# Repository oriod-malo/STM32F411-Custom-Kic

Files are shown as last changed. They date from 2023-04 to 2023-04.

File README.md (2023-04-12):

# STM32F411-Custom-Kit

#### NOTE (as of April 12th 2023)
#### By Kicad ERC and DRC this board should be functional however it's not manufactured yet for a physical, hands-on testing.

## Description

This is my first fully independent KiCad project after following the tutorial for the STM32F103.
A STM32F411 Discovery board was something I wanted to buy since a long time.
However, I figured out it's better if I learn to make myself something similar and have it assembled.<br>
<br>
Due to component density and pin count, this schematic ended up being a 6-layer board. <br>
<br>
Layer parameters and component choice has been made considering jlcpcb constraints and components library(for the sake of orientation). It can be manufactured by ANY service. <br>
Also feel free to change constraints / components. <br>
<br>
<br>

## Differences between this and actual Discovery Boards.

* Due to unavailability of components, I removed all the audio subsystem that Discovery boards have and replaced it with extra pins

* Again due to components availability some components have been replaced with others and / or similar components

* I have no idea how many layers Discovery Kits actually have, this one has 6 layers: Signal(F)/GND/Signal/Signal/Power/Signal(B)

## Installation
1. Create a project called "STM32 Discovery" in KiCad 7.0 (while this is NOT a Discovery kit the name persists from when I first created the project for orientation)

2. Copy all files <except for those in the (previous_sections_files)> from this Git inside the .../Documents/KiCad/7.0/projects/STM32 Discovery

3. Go to the folder "(previous_sections_files)" you will see two subfolders "3dmodels" and "footprints". Copy those in "/Documents/KiCad/7.0/3dmodels" and ""/Documents/KiCad/7.0/footprints" respectively

## Screenshoots






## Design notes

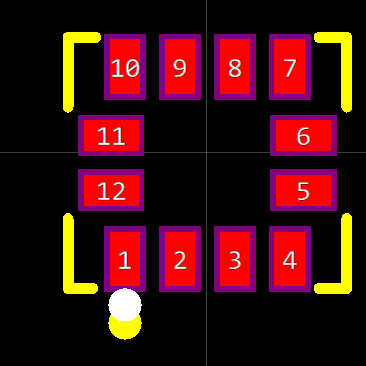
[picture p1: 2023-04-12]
footprint.bmp

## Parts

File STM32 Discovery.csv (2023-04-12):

Comment | Designator | Footprint | LCSC Part #
100n Unpolarized capacitor | C1,C2,C3,C4,C7,C12,C14,C17 | C_0603_1608Metric
1u Unpolarized capacitor | C5,C10,C13,C16 | C_0603_1608Metric
20p Unpolarized capacitor | C6,C9,C67 | C_0603_1608Metric
10n Unpolarized capacitor | C8,C15 | C_0603_1608Metric
100nF Unpolarized capacitor | C11,C21,C23,C25,C26,C29,C30,C31,C32,C34,C35,C37,C55 | C_0603_1608Metric
220nF Unpolarized capacitor | C18 | C_0603_1608Metric
4.7uF Unpolarized capacitor | C19,C57 | C_0603_1608Metric
20pF Unpolarized capacitor | C20,C28 | C_0603_1608Metric
1uF Unpolarized capacitor | C22,C24,C27 | C_0603_1608Metric
2.2uF Unpolarized capacitor | C33,C38 | C_0603_1608Metric
100nf Unpolarized capacitor | C36,C39 | C_0603_1608Metric
10uF Unpolarized capacitor | C40,C43 | C_0603_1608Metric
10nF Unpolarized capacitor | C48 | C_0603_1608Metric
Conn_01x06_Male Generic connector, single row, 01x06, script generated (kicad-library-utils/schlib/autogen/connector/) | CN2 | PinHeader_1x06_P2.54mm_Vertical
Conn_01x04_Male Generic connector, single row, 01x04, script generated (kicad-library-utils/schlib/autogen/connector/) | CN3 | PinHeader_1x04_P2.54mm_Vertical
BAT60JFILM 10V 3A High Current Recitifier Schottky Diode, SOD-323 | D1,D2,D3 | D_SOD-323
LED, red Light emitting diode | D4 | LED_0402_1005Metric
LED_BRGA RGB LED, blue/red/green/anode | D6 | LED_LiteOn_LTST-C295K_1.6x0.8mm
0565790576 0565790576 | J1 | Molex-0565790576-0
Conn_02x08_Odd_Even Generic connector, double row, 02x08, odd/even pin numbering scheme (row 1 odd numbers, row 2 even numbers), script generated (kicad-library-utils/schlib/autogen/connector/) | J2 | IDC-Header_2x08_P2.54mm_Vertical
USB_B_Mini USB Mini Type B connector | J3 | USB_Mini-B_Wuerth_65100516121_Horizontal
Conn_02x25_Odd_Even Generic connector, double row, 02x25, odd/even pin numbering scheme (row 1 odd numbers, row 2 even numbers), script generated (kicad-library-utils/schlib/autogen/connector/) | J4,J5 | IDC-Header_2x25_P2.54mm_Vertical
pin jumper 2.54 1x02 Generic connector, single row, 01x02, script generated | JP2,JP3,JP4 | PinHeader_1x02_P2.54mm_Vertical
Ferrite Inductor | L1 | L_0603_1608Metric
LED, orange Light emitting diode | LD3 | LED_0402_1005Metric
LED, green Light emitting diode | LD4 | LED_0402_1005Metric
LED, red Light emitting diode | LD5 | LED_0402_1005Metric
LED, blue Light emitting diode | LD6 | LED_0402_1005Metric
LED,green Light emitting diode | LD7 | LED_0402_1005Metric
LED,red Light emitting diode | LD8 | LED_0402_1005Metric
S9013 | Q1 | SOT-23
1k5 Resistor | R1 | R_0603_1608Metric
0 Resistor | R2,R6,R7,R11,R22,R26,R29,R33,R42,R48,R55 | R_0603_1608Metric
100 Resistor | R3,R4,R9,R35,R37,R66,R67 | R_0603_1608Metric
100k Resistor | R5,R8,R18 | R_0603_1608Metric
22 Resistor | R10,R15,R16,R17 | R_0603_1608Metric
10k Resistor | R12,R14,R30,R41 | R_0603_1608Metric
1k Resistor | R13,R36,R39 | R_0603_1608Metric
4k7 Resistor | R19,R20,R27,R32 | R_0603_1608Metric
220 Resistor | R21 | R_0603_1608Metric
47 Resistor | R23 | R_0603_1608Metric
510 Resistor | R28,R40 | R_0603_1608Metric
330 Resistor | R34,R38,R64 | R_0603_1608Metric
47k Resistor | R49,R54 | R_0603_1608Metric
620 Resistor | R65 | R_0603_1608Metric
SW_Push Push button switch, generic, two pins | SW1,SW2 | SW_Push_1P1T_NO_6x6mm_H9.5mm
STMPS2141STR | U1 | SOT-23-5
LSM303AGRTR | U2 | LGA12R50P_200X200X100
L3GD20 [Not recommended for new designs] 16-bit 3 Axis Digital MEMS Gyroscope, LGA-16 | U4 | LGA-16_4x4mm_P0.65mm_LayoutBorder4x4y
STM32F411VET6 ARM Cortex-M4 MCU, 512KB flash, 128KB RAM, 100MHz, 1.7-3.6V, 81 GPIO, LQFP-100 | U4A1 | LQFP-100_14x14mm_P0.5mm
STM32F103C8T6 ARM Cortex-M3 MCU, 64KB flash, 20KB RAM, 72MHz, 2-3.6V, 37 GPIO, LQFP-48 | U5 | LQFP-48_7x7mm_P0.5mm
LD3985M25R_SOT23 150mA Low Dropout Voltage Regulator, Fixed Output 2.5V, SOT-23-5 | U6 | SOT-23-5
LD3985M33R_SOT23 150mA Low Dropout Voltage Regulator, Fixed Output 3.3V, SOT-23-5 | U7 | SOT-23-5
8MHz Two pin crystal | X1,X2 | Crystal_SMD_5032-2Pin_5.0x3.2mm

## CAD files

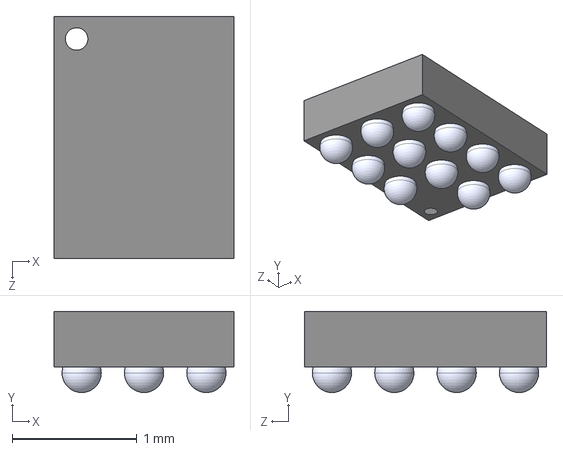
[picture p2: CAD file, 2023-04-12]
3D Model/EMIF02-USB03F2--3DModel-STEP-56544.STEP
1.44 x 0.65 x 1.94 mm

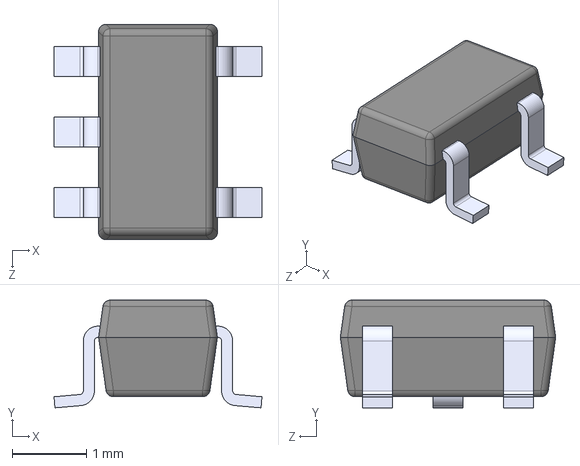
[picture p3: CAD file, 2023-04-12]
footprints/STMPS2141STR.STEP
2.80 x 1.45 x 2.90 mm

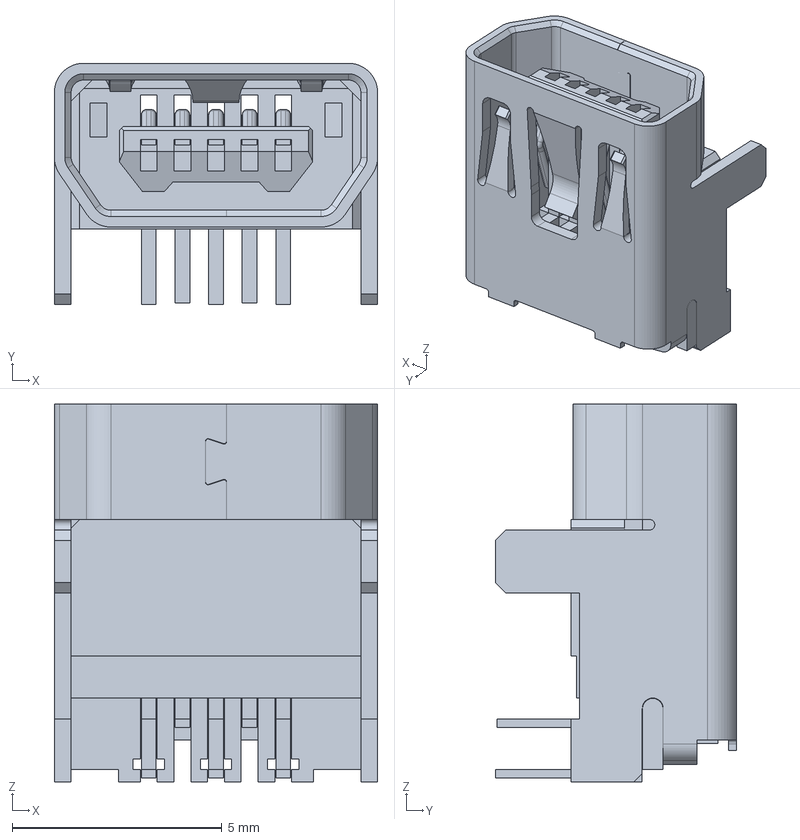
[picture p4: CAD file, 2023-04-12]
3D Model/56579-0519.stp
7.70 x 5.75 x 9.00 mm

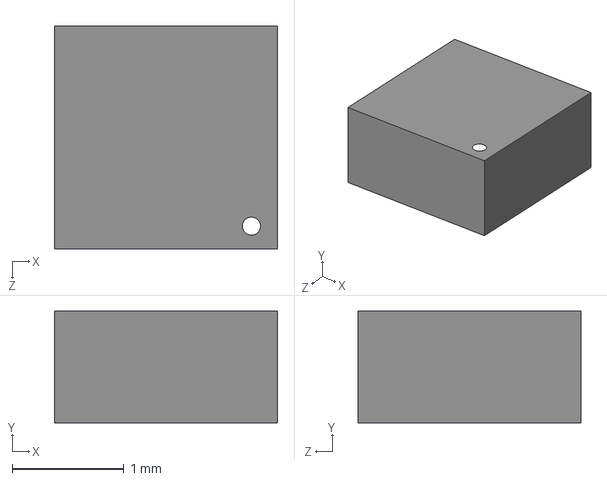
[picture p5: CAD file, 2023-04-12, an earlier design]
(previous_sections_files)/3dmodels/LSM303AGRTR.step
2.00 x 1.00 x 2.00 mm

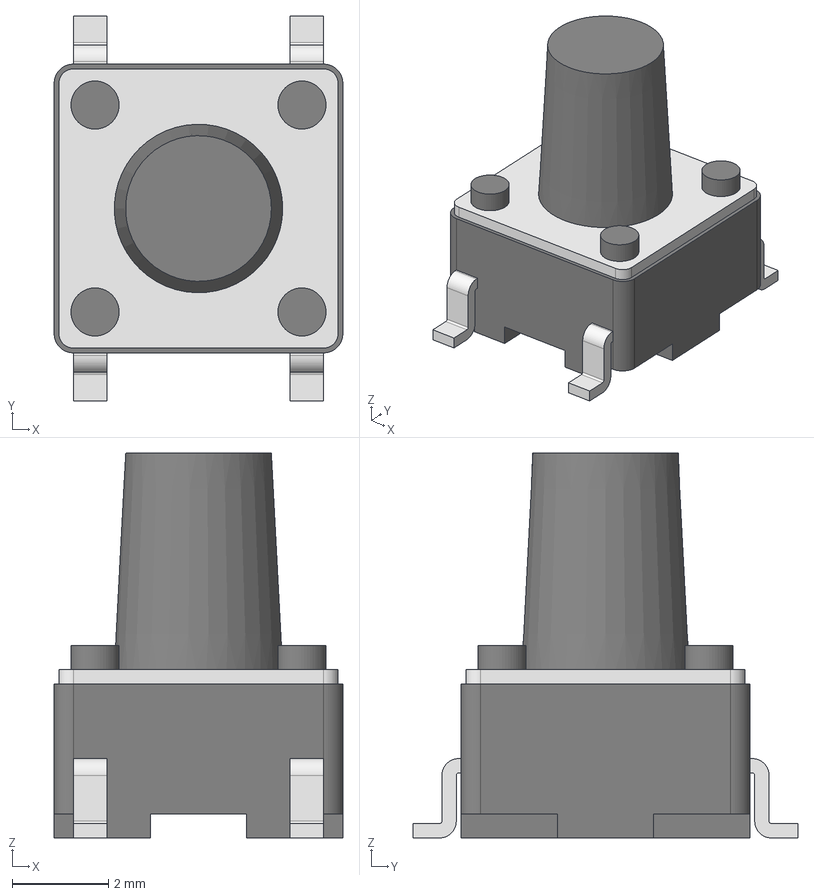
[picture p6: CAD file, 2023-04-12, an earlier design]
(previous_sections_files)/3dmodels/button_smd_6x6x8.0.stp
6.00 x 8.00 x 8.00 mm

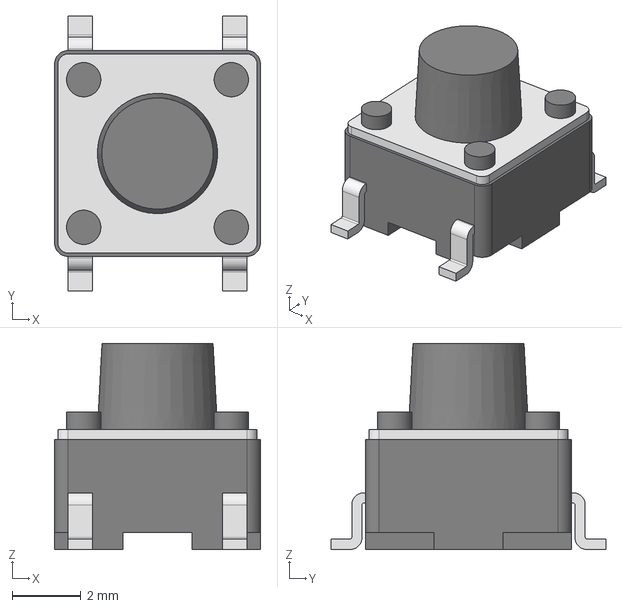
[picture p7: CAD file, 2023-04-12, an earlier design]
(previous_sections_files)/3dmodels/button_smd_6x6x6.0.stp
6.00 x 8.00 x 6.00 mm

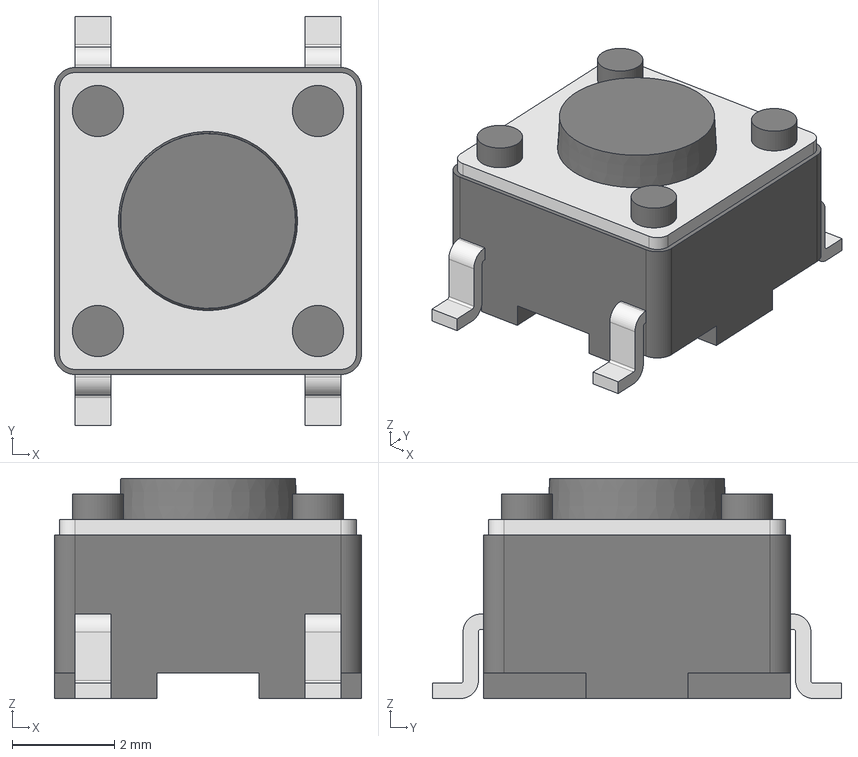
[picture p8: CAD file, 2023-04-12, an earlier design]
(previous_sections_files)/3dmodels/button_smd_6x6x4.3.stp
6.00 x 8.00 x 4.30 mm

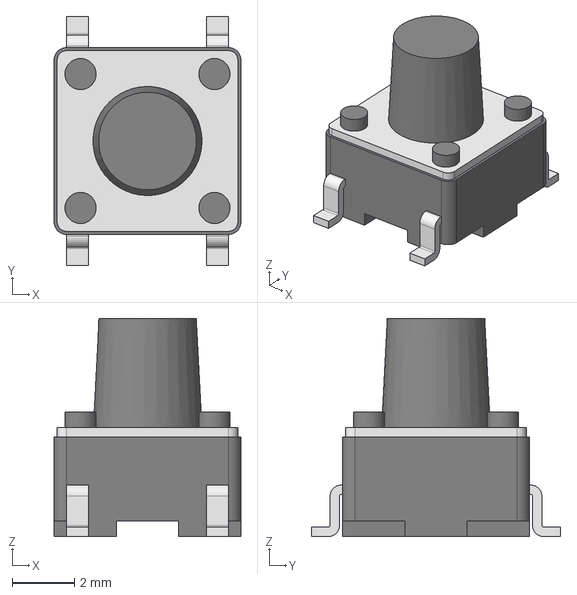
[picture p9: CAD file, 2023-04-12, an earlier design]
(previous_sections_files)/3dmodels/button_smd_6x6x7.0.stp
6.00 x 8.00 x 7.00 mm

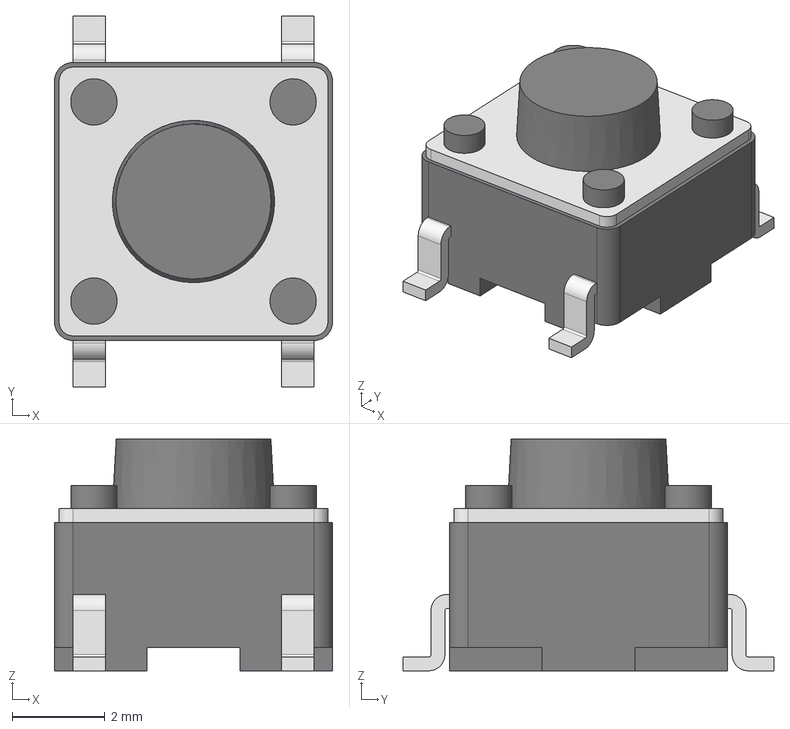
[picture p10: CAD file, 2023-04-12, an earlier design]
(previous_sections_files)/3dmodels/button_smd_6x6x5.0.stp
6.00 x 8.00 x 5.00 mm

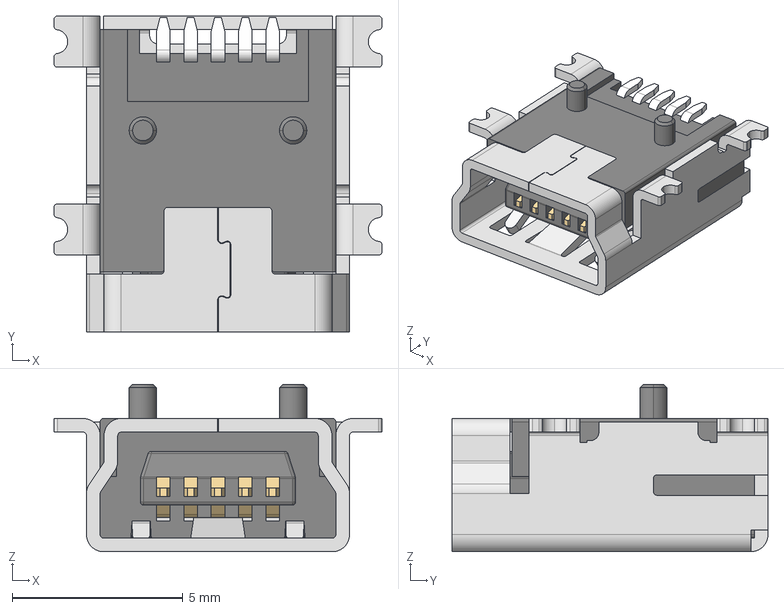
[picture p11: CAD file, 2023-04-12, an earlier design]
(previous_sections_files)/3dmodels/65100516121.step
9.60 x 9.25 x 4.90 mm

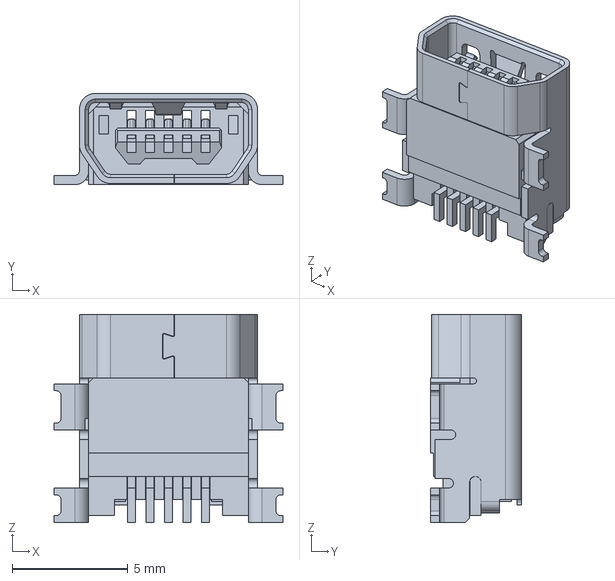
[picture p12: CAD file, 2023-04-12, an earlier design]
(previous_sections_files)/3dmodels/565790576.stp
9.90 x 3.95 x 9.00 mm

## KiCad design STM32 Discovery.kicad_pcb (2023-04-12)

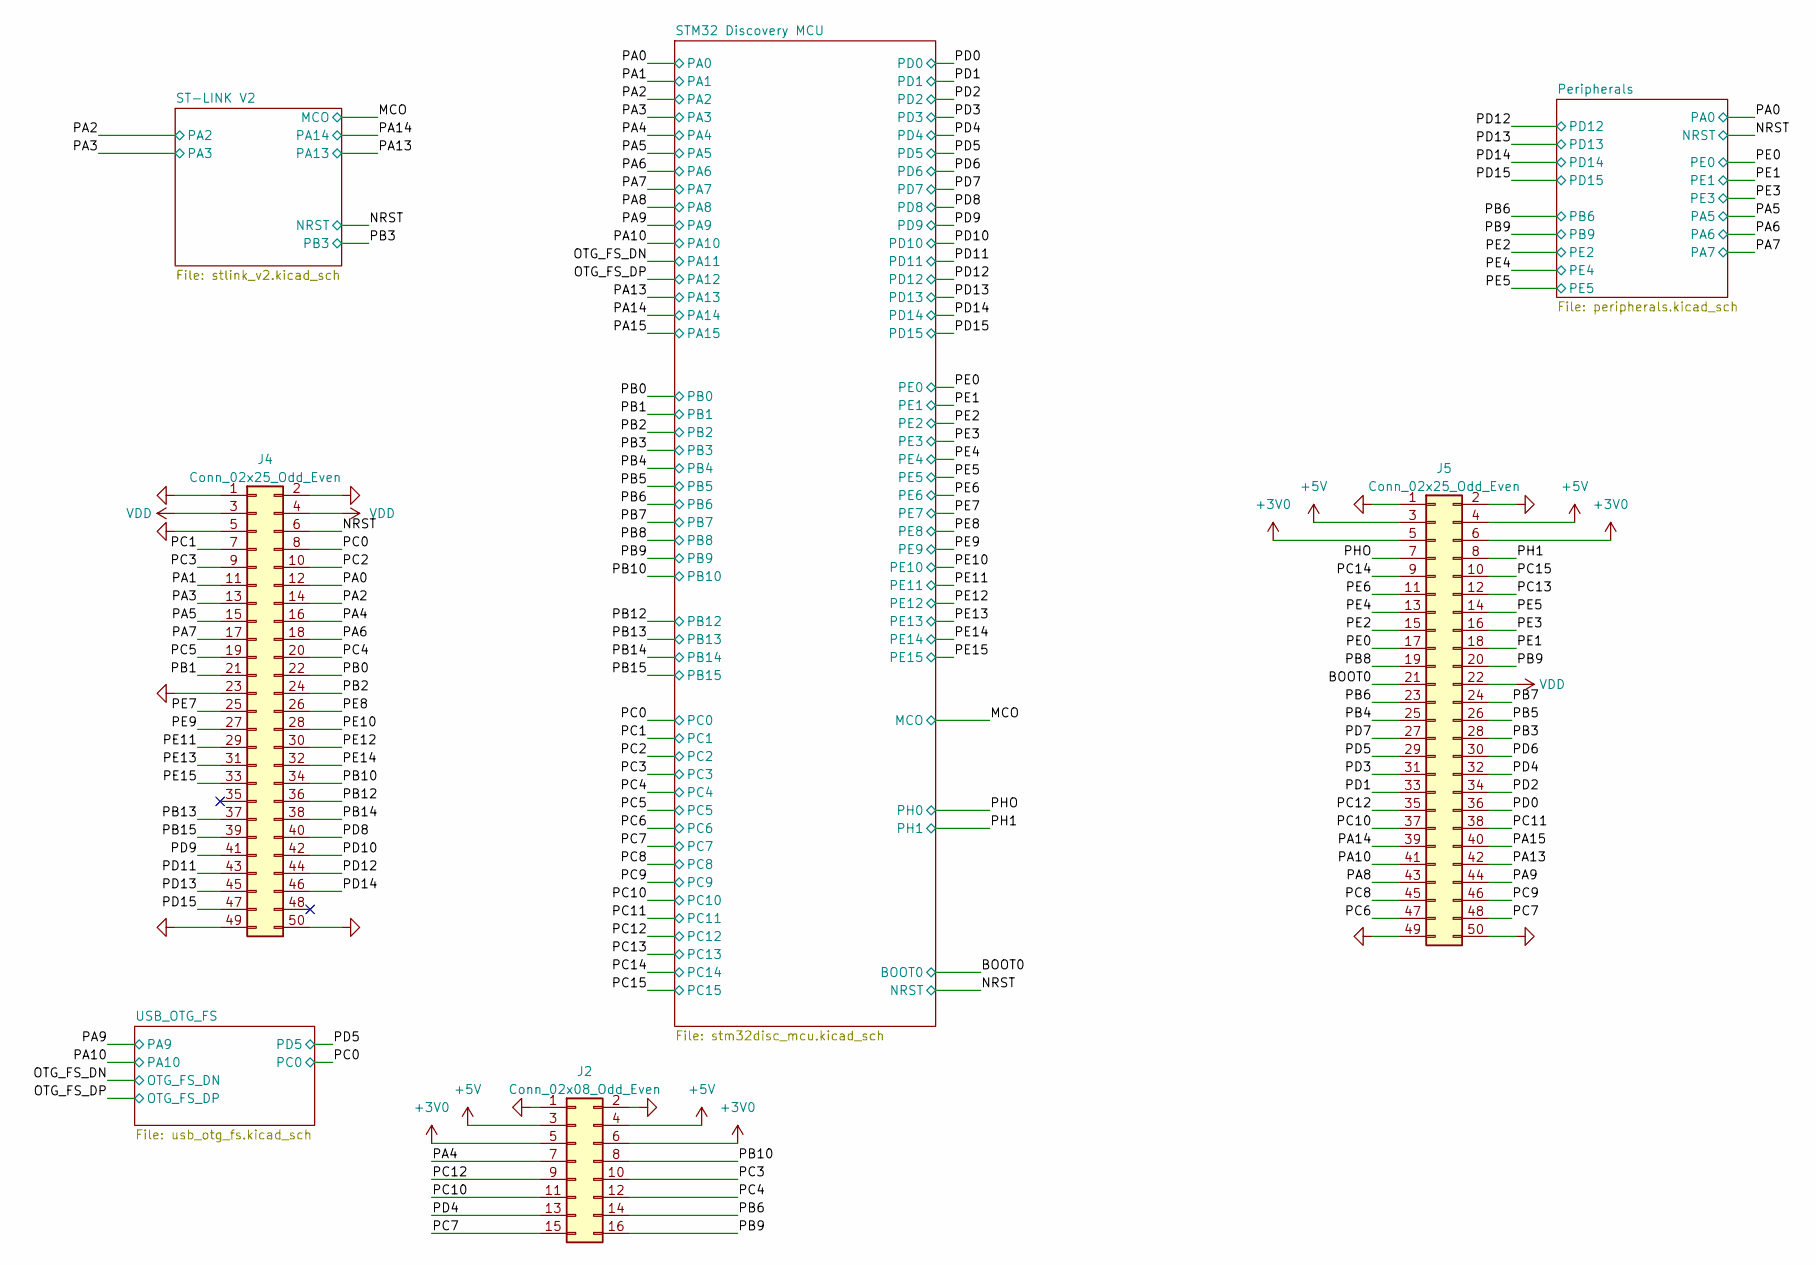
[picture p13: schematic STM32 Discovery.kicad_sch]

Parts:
J2: Conn_02x08_Odd_Even; PinHeader_2x08_P2.54mm_Vertical
J4, J5: Conn_02x25_Odd_Even; PinHeader_2x25_P2.54mm_Vertical

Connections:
+3V0: J2.5, J2.6, J5.5, J5.6; also elsewhere on the board
+5V: J2.3, J2.4, J5.3, J5.4; also elsewhere on the board
/BOOT0: J5.21; also elsewhere on the board
/NRST: J4.6; also elsewhere on the board
/PA0: J4.12; also elsewhere on the board
/PA1: J4.11; also elsewhere on the board
/PA2: J4.14; also elsewhere on the board
/PA3: J4.13; also elsewhere on the board
/PA4: J2.7, J4.16; also elsewhere on the board
/PA5: J4.15; also elsewhere on the board
/PA6: J4.18; also elsewhere on the board
/PA7: J4.17; also elsewhere on the board
/PA8: J5.43; also elsewhere on the board
/PA9: J5.44; also elsewhere on the board
/PA10: J5.41; also elsewhere on the board
/PA13: J5.42; also elsewhere on the board
/PA14: J5.39; also elsewhere on the board
/PA15: J5.40; also elsewhere on the board
/PB0: J4.22; also elsewhere on the board
/PB1: J4.21; also elsewhere on the board
/PB2: J4.24; also elsewhere on the board
/PB3: J5.28; also elsewhere on the board
/PB4: J5.25; also elsewhere on the board
/PB5: J5.26; also elsewhere on the board
/PB6: J2.14, J5.23; also elsewhere on the board
/PB7: J5.24; also elsewhere on the board
/PB8: J5.19; also elsewhere on the board
/PB9: J2.16, J5.20; also elsewhere on the board
/PB10: J2.8, J4.34; also elsewhere on the board
/PB12: J4.36; also elsewhere on the board
/PB13: J4.37; also elsewhere on the board
/PB14: J4.38; also elsewhere on the board
/PB15: J4.39; also elsewhere on the board
/PC0: J4.8; also elsewhere on the board
/PC1: J4.7; also elsewhere on the board
/PC2: J4.10; also elsewhere on the board
/PC3: J2.10, J4.9; also elsewhere on the board
/PC4: J2.12, J4.20; also elsewhere on the board
/PC5: J4.19; also elsewhere on the board
/PC6: J5.47; also elsewhere on the board
/PC7: J2.15, J5.48; also elsewhere on the board
/PC8: J5.45; also elsewhere on the board
/PC9: J5.46; also elsewhere on the board
/PC10: J2.11, J5.37; also elsewhere on the board
/PC11: J5.38; also elsewhere on the board
/PC12: J2.9, J5.35; also elsewhere on the board
/PC13: J5.12; also elsewhere on the board
/PC14: J5.9; also elsewhere on the board
/PC15: J5.10; also elsewhere on the board
/PD0: J5.36; also elsewhere on the board
/PD1: J5.33; also elsewhere on the board
/PD2: J5.34; also elsewhere on the board
/PD3: J5.31; also elsewhere on the board
/PD4: J2.13, J5.32; also elsewhere on the board
/PD5: J5.29; also elsewhere on the board
/PD6: J5.30; also elsewhere on the board
/PD7: J5.27; also elsewhere on the board
/PD8: J4.40; also elsewhere on the board
/PD9: J4.41; also elsewhere on the board
/PD10: J4.42; also elsewhere on the board
/PD11: J4.43; also elsewhere on the board
/PD12: J4.44; also elsewhere on the board
/PD13: J4.45; also elsewhere on the board
/PD14: J4.46; also elsewhere on the board
/PD15: J4.47; also elsewhere on the board
/PE0: J5.17; also elsewhere on the board
/PE1: J5.18; also elsewhere on the board
/PE2: J5.15; also elsewhere on the board
/PE3: J5.16; also elsewhere on the board
/PE4: J5.13; also elsewhere on the board
/PE5: J5.14; also elsewhere on the board
/PE6: J5.11; also elsewhere on the board
/PE7: J4.25; also elsewhere on the board
/PE8: J4.26; also elsewhere on the board
/PE9: J4.27; also elsewhere on the board
/PE10: J4.28; also elsewhere on the board
/PE11: J4.29; also elsewhere on the board
/PE12: J4.30; also elsewhere on the board
/PE13: J4.31; also elsewhere on the board
/PE14: J4.32; also elsewhere on the board
/PE15: J4.33; also elsewhere on the board
/PH1: J5.8; also elsewhere on the board
/PHO: J5.7; also elsewhere on the board
GND: J2.1, J2.2, J4.1, J4.2, J4.5, J4.23, J4.49, J4.50, J5.1, J5.2, J5.49, J5.50; also elsewhere on the board
VDD: J4.3, J4.4, J5.22; also elsewhere on the board

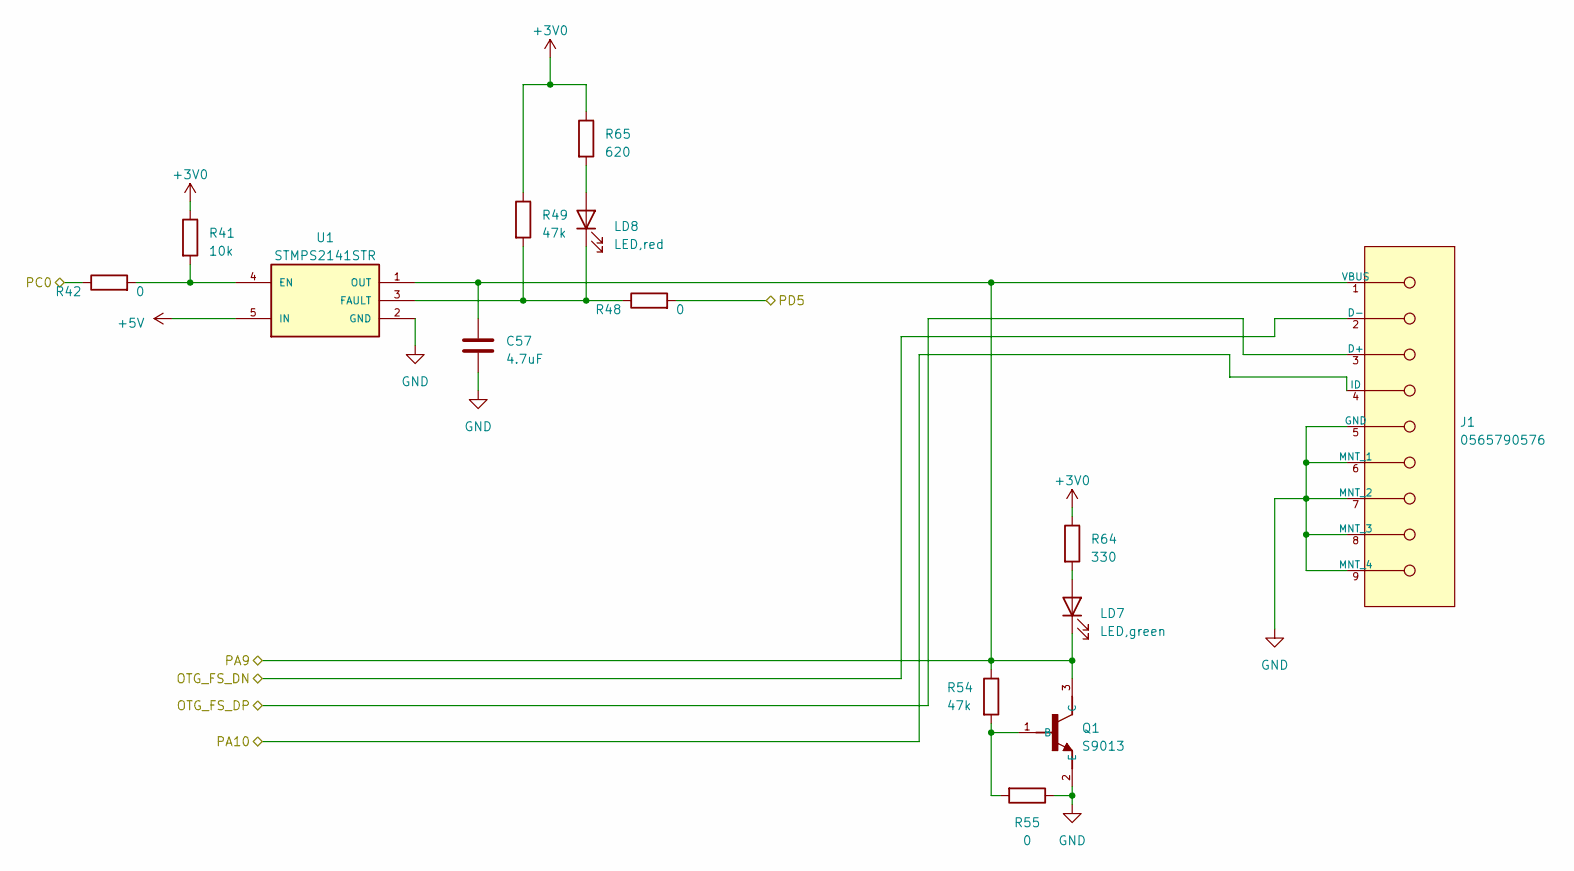
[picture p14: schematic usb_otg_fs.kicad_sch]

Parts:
C57: 4.7uF; C_0402_1005Metric
J1: 0565790576; Molex-0565790576-0; voltage 30VAC/DC; mouser part number 538-56579-0576; digikey description CONN RECEPT USB 5POS RT ANG SMD
LD7: LED,green; LED_0402_1005Metric
LD8: LED,red; LED_0402_1005Metric
Q1: S9013; SOT-23
R41: 10k; R_0402_1005Metric
R42, R48, R55: 0; R_0402_1005Metric
R49, R54: 47k; R_0402_1005Metric
R64: 330; R_0402_1005Metric
R65: 620; R_0402_1005Metric
U1: STMPS2141STR; SOT-23-5

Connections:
+3V0: R41.1, R49.1, R64.1, R65.1; also elsewhere on the board
+5V: U1.5 (IN); also elsewhere on the board
/OTG_FS_DN: J1.2 (D-); also elsewhere on the board
/OTG_FS_DP: J1.3 (D+); also elsewhere on the board
/PA9: C57.1, J1.1 (VBUS), LD7.1 (K), Q1.3 (C), R54.1, U1.1 (OUT); also elsewhere on the board
/PA10: J1.4 (ID); also elsewhere on the board
/PC0: R42.1; also elsewhere on the board
/PD5: R48.2; also elsewhere on the board
GND: C57.2, J1.5 (GND), J1.6 (MNT_1), J1.7 (MNT_2), J1.8 (MNT_3), J1.9 (MNT_4), Q1.2 (E), R55.1, U1.2 (GND); also elsewhere on the board
unnamed: LD7.2 (A), R64.2
unnamed: LD8.2 (A), R65.2
unnamed: LD8.1 (K), R48.1, R49.2, U1.3 (FAULT)
unnamed: Q1.1 (B), R54.2, R55.2
unnamed: R41.2, R42.2, U1.4 (EN)

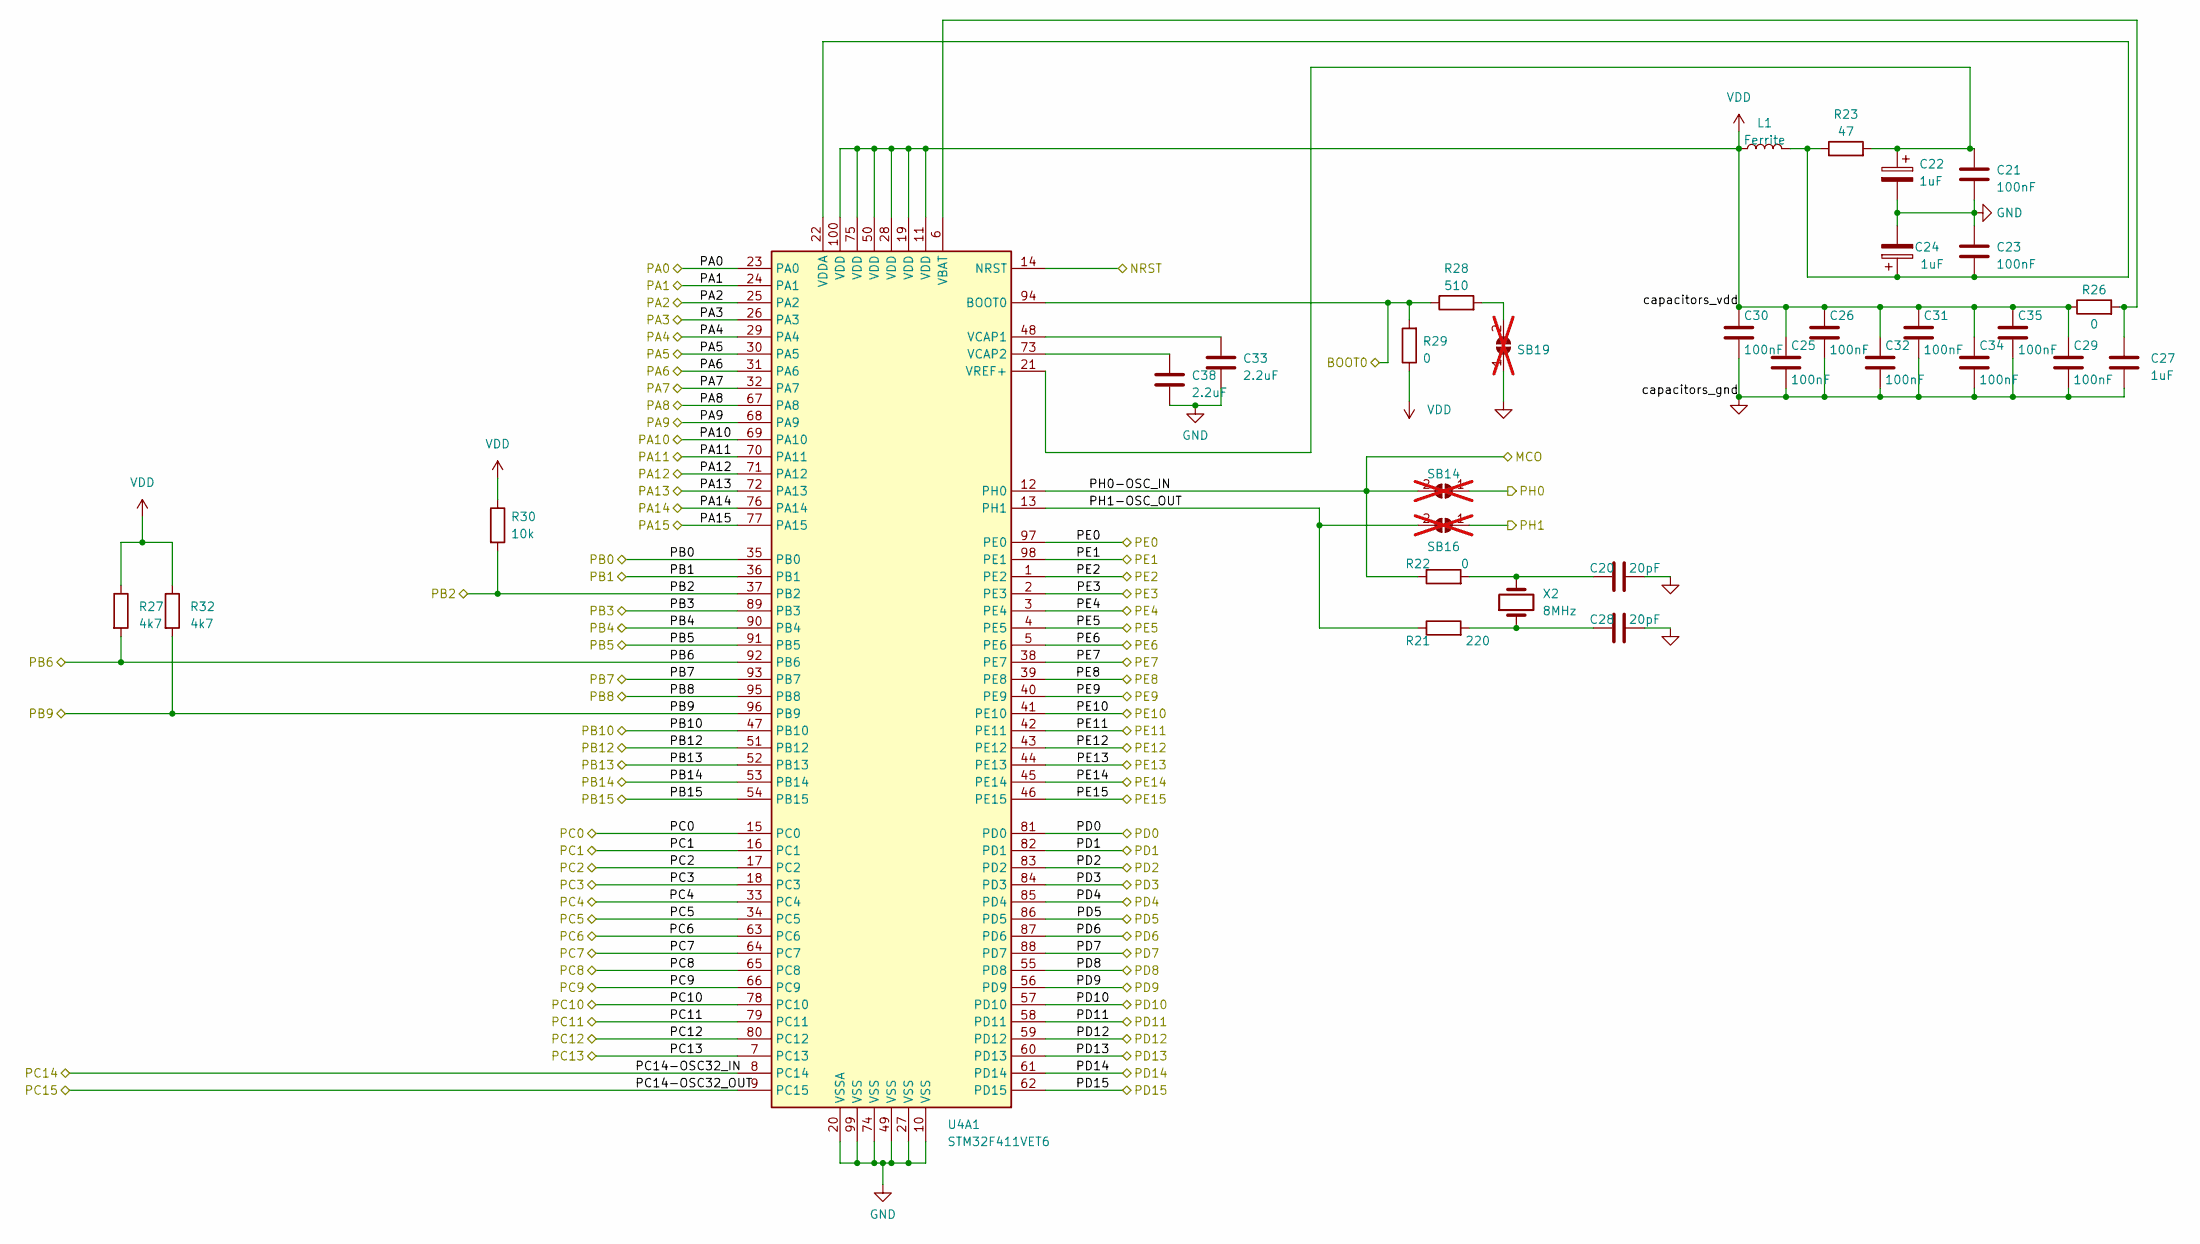
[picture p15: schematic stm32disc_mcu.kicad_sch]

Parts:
C20, C28: 20pF; C_0402_1005Metric
C21, C23, C25, C26, C29, C30, C31, C32, C34, C35: 100nF; C_0402_1005Metric
C22, C24, C27: 1uF; C_0402_1005Metric
C33, C38: 2.2uF; C_0402_1005Metric
L1: Ferrite; L_0603_1608Metric
R21: 220; R_0402_1005Metric
R22, R26, R29: 0; R_0402_1005Metric
R23: 47; R_0402_1005Metric
R27, R32: 4k7; R_0402_1005Metric
R28: 510; R_0402_1005Metric
R30: 10k; R_0402_1005Metric
SB14, SB16, SB19: SolderJumper_2_Open; SolderJumper-2_P1.3mm_Open_TrianglePad1.0x1.5mm; not fitted
U4A1: STM32F411VET6; LQFP-100_14x14mm_P0.5mm
X2: 8MHz; Crystal_SMD_5032-2Pin_5.0x3.2mm

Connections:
/BOOT0: R28.1, R29.2, U4A1.94 (BOOT0); also elsewhere on the board
/MCO: R22.1, SB14.2 (B), U4A1.12 (PH0); also elsewhere on the board
/NRST: U4A1.14 (NRST); also elsewhere on the board
/OTG_FS_DN: U4A1.70 (PA11); also elsewhere on the board
/OTG_FS_DP: U4A1.71 (PA12); also elsewhere on the board
/PA0: U4A1.23 (PA0); also elsewhere on the board
/PA1: U4A1.24 (PA1); also elsewhere on the board
/PA2: U4A1.25 (PA2); also elsewhere on the board
/PA3: U4A1.26 (PA3); also elsewhere on the board
/PA4: U4A1.29 (PA4); also elsewhere on the board
/PA5: U4A1.30 (PA5); also elsewhere on the board
/PA6: U4A1.31 (PA6); also elsewhere on the board
/PA7: U4A1.32 (PA7); also elsewhere on the board
/PA8: U4A1.67 (PA8); also elsewhere on the board
/PA9: U4A1.68 (PA9); also elsewhere on the board
/PA10: U4A1.69 (PA10); also elsewhere on the board
/PA13: U4A1.72 (PA13); also elsewhere on the board
/PA14: U4A1.76 (PA14); also elsewhere on the board
/PA15: U4A1.77 (PA15); also elsewhere on the board
/PB0: U4A1.35 (PB0); also elsewhere on the board
/PB1: U4A1.36 (PB1); also elsewhere on the board
/PB2: R30.2, U4A1.37 (PB2); also elsewhere on the board
/PB3: U4A1.89 (PB3); also elsewhere on the board
/PB4: U4A1.90 (PB4); also elsewhere on the board
/PB5: U4A1.91 (PB5); also elsewhere on the board
/PB6: R27.2, U4A1.92 (PB6); also elsewhere on the board
/PB7: U4A1.93 (PB7); also elsewhere on the board
/PB8: U4A1.95 (PB8); also elsewhere on the board
/PB9: R32.2, U4A1.96 (PB9); also elsewhere on the board
/PB10: U4A1.47 (PB10); also elsewhere on the board
/PB12: U4A1.51 (PB12); also elsewhere on the board
/PB13: U4A1.52 (PB13); also elsewhere on the board
/PB14: U4A1.53 (PB14); also elsewhere on the board
/PB15: U4A1.54 (PB15); also elsewhere on the board
/PC0: U4A1.15 (PC0); also elsewhere on the board
/PC1: U4A1.16 (PC1); also elsewhere on the board
/PC2: U4A1.17 (PC2); also elsewhere on the board
/PC3: U4A1.18 (PC3); also elsewhere on the board
/PC4: U4A1.33 (PC4); also elsewhere on the board
/PC5: U4A1.34 (PC5); also elsewhere on the board
/PC6: U4A1.63 (PC6); also elsewhere on the board
/PC7: U4A1.64 (PC7); also elsewhere on the board
/PC8: U4A1.65 (PC8); also elsewhere on the board
/PC9: U4A1.66 (PC9); also elsewhere on the board
/PC10: U4A1.78 (PC10); also elsewhere on the board
/PC11: U4A1.79 (PC11); also elsewhere on the board
/PC12: U4A1.80 (PC12); also elsewhere on the board
/PC13: U4A1.7 (PC13); also elsewhere on the board
/PC14: U4A1.8 (PC14); also elsewhere on the board
/PC15: U4A1.9 (PC15); also elsewhere on the board
/PD0: U4A1.81 (PD0); also elsewhere on the board
/PD1: U4A1.82 (PD1); also elsewhere on the board
/PD2: U4A1.83 (PD2); also elsewhere on the board
/PD3: U4A1.84 (PD3); also elsewhere on the board
/PD4: U4A1.85 (PD4); also elsewhere on the board
/PD5: U4A1.86 (PD5); also elsewhere on the board
/PD6: U4A1.87 (PD6); also elsewhere on the board
/PD7: U4A1.88 (PD7); also elsewhere on the board
/PD8: U4A1.55 (PD8); also elsewhere on the board
/PD9: U4A1.56 (PD9); also elsewhere on the board
/PD10: U4A1.57 (PD10); also elsewhere on the board
/PD11: U4A1.58 (PD11); also elsewhere on the board
/PD12: U4A1.59 (PD12); also elsewhere on the board
/PD13: U4A1.60 (PD13); also elsewhere on the board
/PD14: U4A1.61 (PD14); also elsewhere on the board
/PD15: U4A1.62 (PD15); also elsewhere on the board
/PE0: U4A1.97 (PE0); also elsewhere on the board
/PE1: U4A1.98 (PE1); also elsewhere on the board
/PE2: U4A1.1 (PE2); also elsewhere on the board
/PE3: U4A1.2 (PE3); also elsewhere on the board
/PE4: U4A1.3 (PE4); also elsewhere on the board
/PE5: U4A1.4 (PE5); also elsewhere on the board
/PE6: U4A1.5 (PE6); also elsewhere on the board
/PE7: U4A1.38 (PE7); also elsewhere on the board
/PE8: U4A1.39 (PE8); also elsewhere on the board
/PE9: U4A1.40 (PE9); also elsewhere on the board
/PE10: U4A1.41 (PE10); also elsewhere on the board
/PE11: U4A1.42 (PE11); also elsewhere on the board
/PE12: U4A1.43 (PE12); also elsewhere on the board
/PE13: U4A1.44 (PE13); also elsewhere on the board
/PE14: U4A1.45 (PE14); also elsewhere on the board
/PE15: U4A1.46 (PE15); also elsewhere on the board
/PH1: SB16.1 (A); also elsewhere on the board
/PHO: SB14.1 (A); also elsewhere on the board
/STM32 Discovery MCU/PH1-OSC_OUT: R21.1, SB16.2 (B), U4A1.13 (PH1)
GND: C20.2, C21.2, C22.2, C23.1, C24.2, C25.2, C26.2, C27.2, C28.2, C29.2, C30.2, C31.2, C32.2, C33.2, C34.2, C35.2, C38.2, SB19.1 (A), U4A1.10 (VSS), U4A1.20 (VSSA), U4A1.27 (VSS), U4A1.49 (VSS), U4A1.74 (VSS), U4A1.99 (VSS); also elsewhere on the board
unnamed: C20.1, R22.2, X2.2
unnamed: C28.1, R21.2, X2.1
unnamed: R28.2, SB19.2 (B)
unnamed: C27.1, R26.2, U4A1.6 (VBAT)
unnamed: C33.1, U4A1.48 (VCAP1)
unnamed: C38.1, U4A1.73 (VCAP2)
unnamed: C23.2, C24.1, L1.2, R23.1, U4A1.22 (VDDA)
unnamed: C21.1, C22.1, R23.2, U4A1.21 (VREF+)
VDD: C25.1, C26.1, C29.1, C30.1, C31.1, C32.1, C34.1, C35.1, L1.1, R26.1, R27.1, R29.1, R30.1, R32.1, U4A1.11 (VDD), U4A1.19 (VDD), U4A1.28 (VDD), U4A1.50 (VDD), U4A1.75 (VDD), U4A1.100 (VDD); also elsewhere on the board

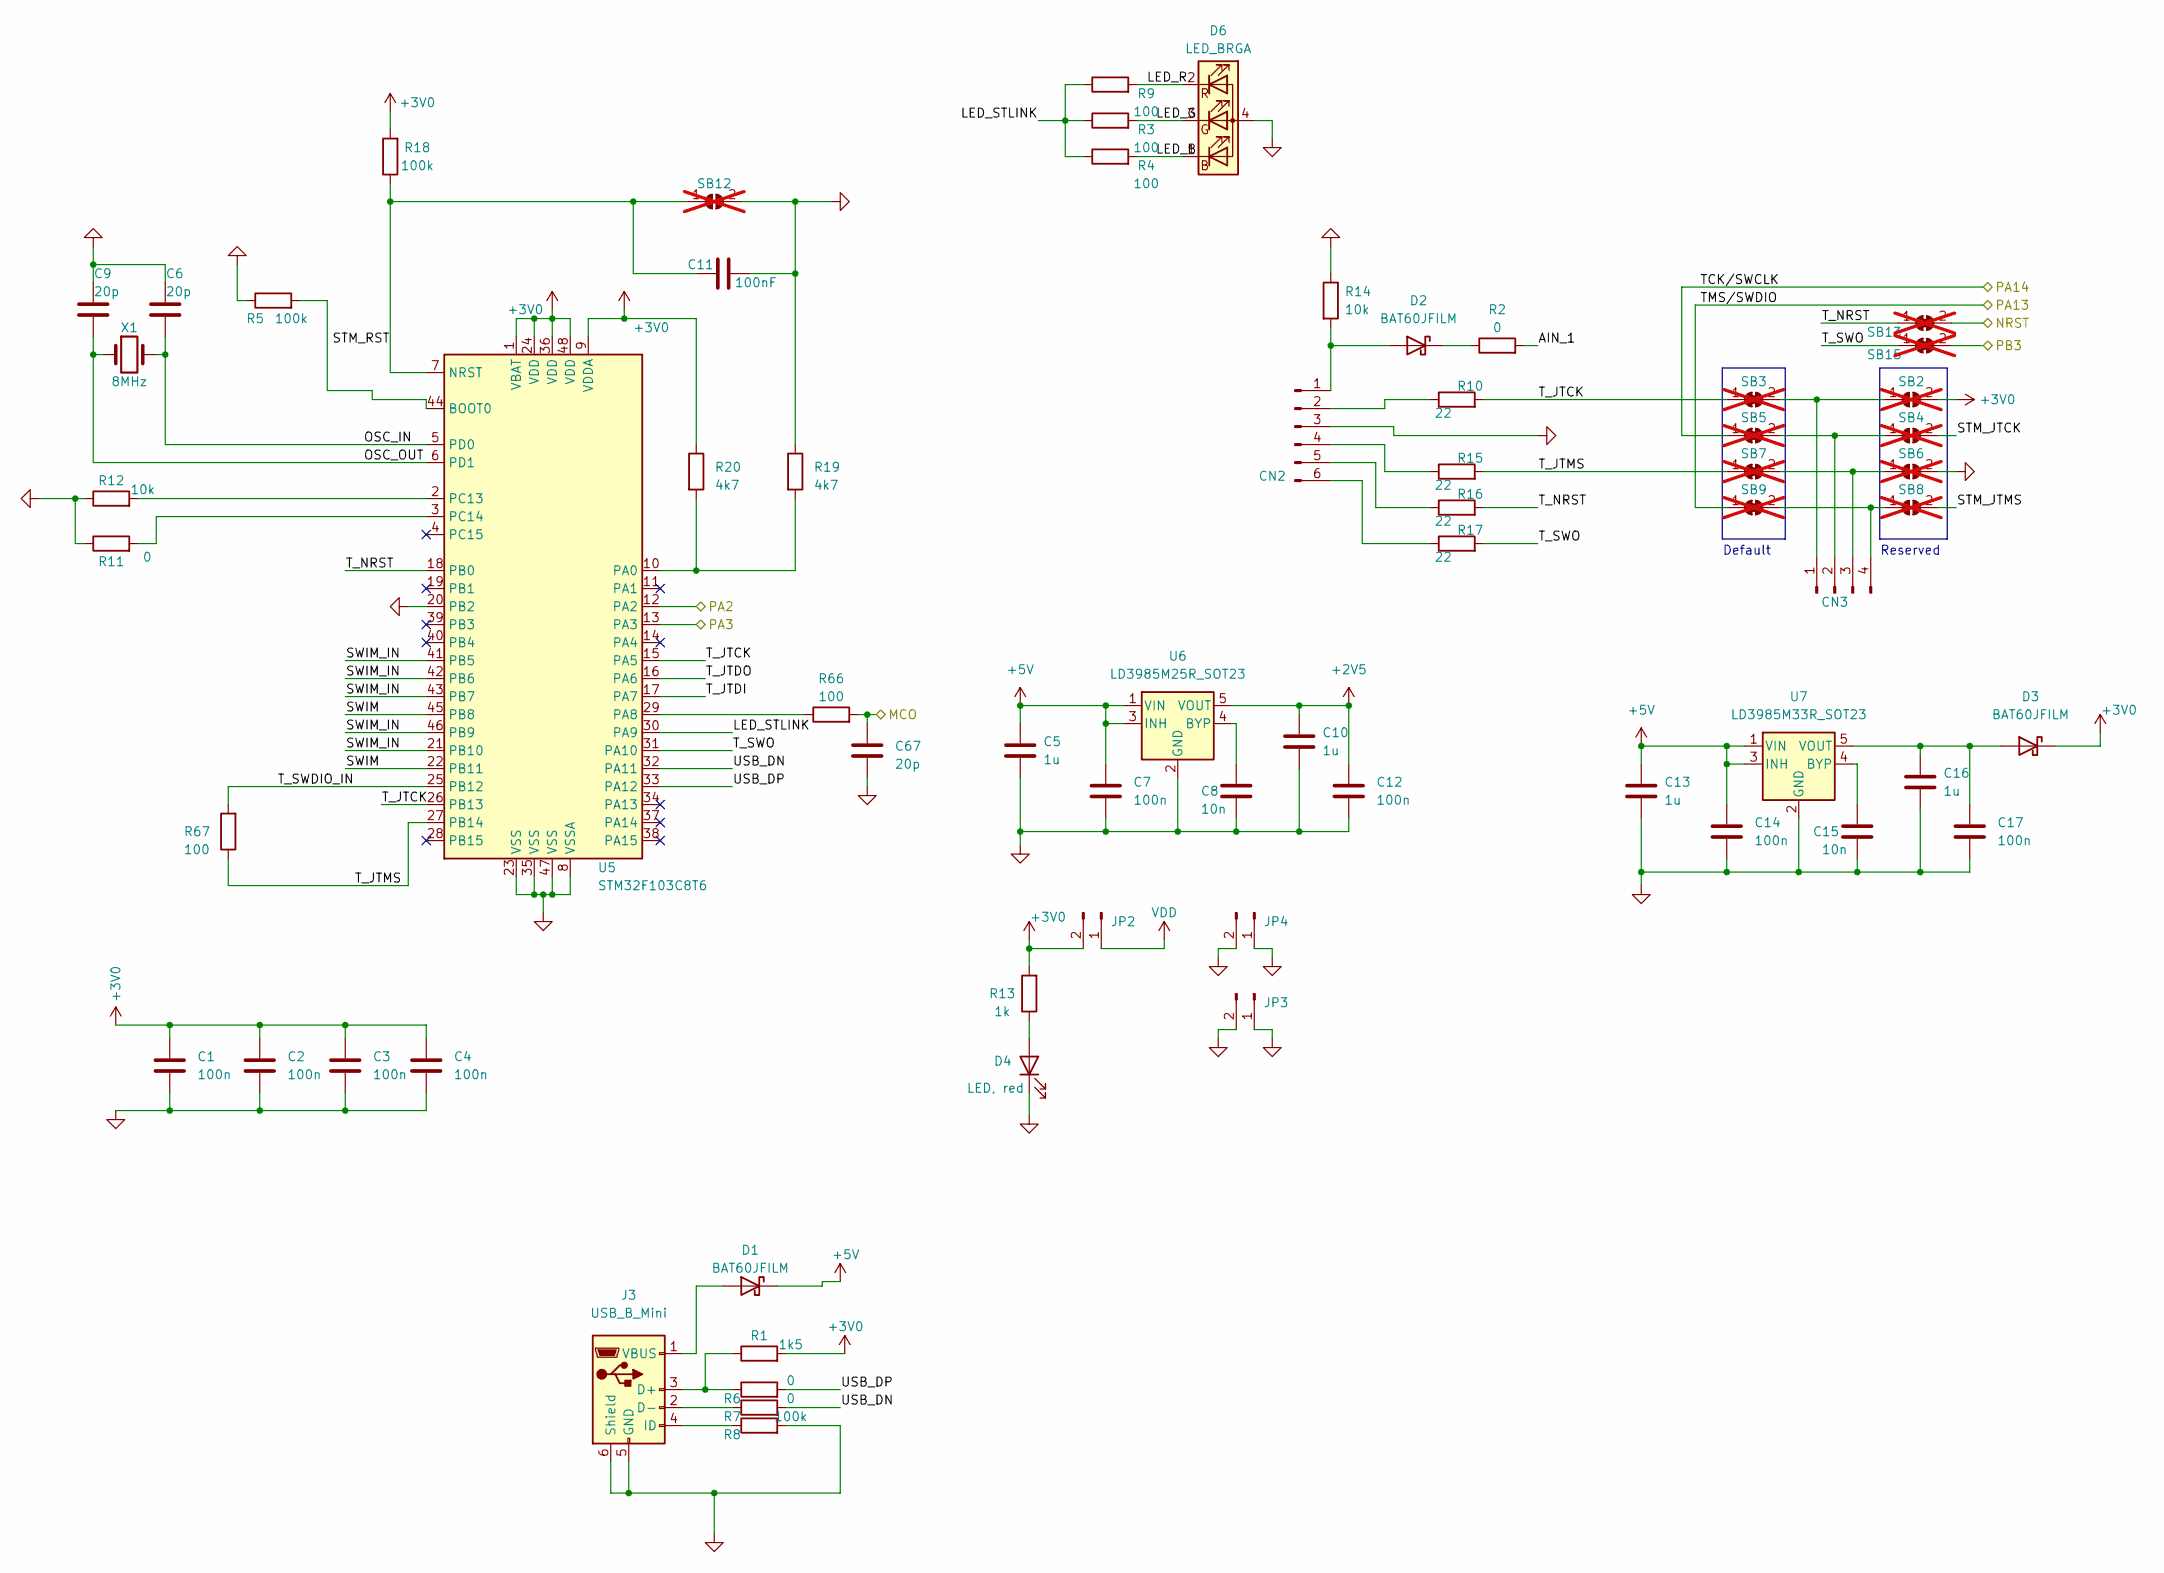
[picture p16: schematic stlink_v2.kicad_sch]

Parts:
C1, C2, C3, C4, C7, C12, C14, C17: 100n; C_0402_1005Metric
C5, C10, C13, C16: 1u; C_0402_1005Metric
C6, C9, C67: 20p; C_0402_1005Metric
C8, C15: 10n; C_0402_1005Metric
C11: 100nF; C_0402_1005Metric
CN2: Conn_01x06_Male; PinHeader_1x06_P2.54mm_Vertical
CN3: Conn_01x04_Male; PinHeader_1x04_P2.54mm_Vertical
D1, D2, D3: BAT60JFILM; D_SOD-323
D4: LED, red; LED_0402_1005Metric
D6: LED_BRGA; LED_LiteOn_LTST-C295K_1.6x0.8mm
J3: USB_B_Mini; USB_Mini-B_Wuerth_65100516121_Horizontal
JP2, JP3, JP4: pin jumper 2.54 1x02; PinHeader_1x02_P2.54mm_Vertical
R1: 1k5; R_0402_1005Metric
R2, R6, R7, R11: 0; R_0402_1005Metric
R3, R4, R9, R66, R67: 100; R_0402_1005Metric
R5, R8, R18: 100k; R_0402_1005Metric
R10, R15, R16, R17: 22; R_0402_1005Metric
R12, R14: 10k; R_0402_1005Metric
R13: 1k; R_0402_1005Metric
R19, R20: 4k7; R_0402_1005Metric
SB2, SB4, SB6, SB8, SB12: SolderJumper_2_Open; SolderJumper-2_P1.3mm_Open_TrianglePad1.0x1.5mm; not fitted
SB3, SB5, SB7, SB9, SB13, SB15: SolderJumper_2_Bridged; SolderJumper-2_P1.3mm_Bridged2Bar_Pad1.0x1.5mm; not fitted
U5: STM32F103C8T6; LQFP-48_7x7mm_P0.5mm
U6: LD3985M25R_SOT23; SOT-23-5
U7: LD3985M33R_SOT23; SOT-23-5
X1: 8MHz; Crystal_SMD_5032-2Pin_5.0x3.2mm

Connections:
+2V5: C10.1, C12.1, U6.5 (VOUT)
+3V0: C1.1, C2.1, C3.1, C4.1, D3.1 (K), JP2.2, R1.2, R13.2, R18.2, R20.1, SB2.2 (B), U5.1 (VBAT), U5.9 (VDDA), U5.24 (VDD), U5.36 (VDD), U5.48 (VDD); also elsewhere on the board
+5V: C5.1, C7.1, C13.1, C14.1, D1.1 (K), U6.1 (VIN), U6.3 (INH), U7.1 (VIN), U7.3 (INH); also elsewhere on the board
/MCO: C67.1, R66.2; also elsewhere on the board
/NRST: SB13.2 (B); also elsewhere on the board
/PA2: U5.12 (PA2); also elsewhere on the board
/PA3: U5.13 (PA3); also elsewhere on the board
/PA13: SB9.1 (A); also elsewhere on the board
/PA14: SB5.1 (A); also elsewhere on the board
/PB3: SB15.2 (B); also elsewhere on the board
/ST-LINK V2/AIN_1: R2.2
/ST-LINK V2/LED_B: D6.1 (BK), R4.2
/ST-LINK V2/LED_G: D6.3 (GK), R3.2
/ST-LINK V2/LED_R: D6.2 (RK), R9.2
/ST-LINK V2/LED_STLINK: R3.1, R4.1, R9.1, U5.30 (PA9)
/ST-LINK V2/OSC_IN: C6.2, U5.5 (PD0), X1.2
/ST-LINK V2/OSC_OUT: C9.2, U5.6 (PD1), X1.1
/ST-LINK V2/STM_JTCK: SB4.2 (B)
/ST-LINK V2/STM_JTMS: SB8.2 (B)
/ST-LINK V2/STM_RST: C11.1, R18.1, SB12.1 (A), U5.7 (NRST)
/ST-LINK V2/SWIM: U5.22 (PB11), U5.45 (PB8)
/ST-LINK V2/SWIM_IN: U5.21 (PB10), U5.41 (PB5), U5.42 (PB6), U5.43 (PB7), U5.46 (PB9)
/ST-LINK V2/T_JTCK: R10.2, SB3.1 (A), U5.15 (PA5), U5.26 (PB13)
/ST-LINK V2/T_JTDI: U5.17 (PA7)
/ST-LINK V2/T_JTDO: U5.16 (PA6)
/ST-LINK V2/T_JTMS: R15.2, R67.1, SB7.1 (A), U5.27 (PB14)
/ST-LINK V2/T_NRST: R16.2, SB13.1 (A), U5.18 (PB0)
/ST-LINK V2/T_SWDIO_IN: R67.2, U5.25 (PB12)
/ST-LINK V2/T_SWO: R17.2, SB15.1 (A), U5.31 (PA10)
/ST-LINK V2/USB_DN: R7.2, U5.32 (PA11)
/ST-LINK V2/USB_DP: R6.2, U5.33 (PA12)
GND: C1.2, C2.2, C3.2, C4.2, C5.2, C6.1, C7.2, C8.2, C9.1, C10.2, C11.2, C12.2, C13.2, C14.2, C15.2, C16.2, C17.2, C67.2, CN2.3, D4.1 (K), D6.4 (A), J3.5 (GND), J3.6 (Shield), JP3.1, JP3.2, JP4.1, JP4.2, R5.1, R8.2, R11.1, R12.1, R14.1, R19.1, SB6.2 (B), SB12.2 (B), U5.8 (VSSA), U5.20 (PB2), U5.23 (VSS), U5.35 (VSS), U5.47 (VSS), U6.2 (GND), U7.2 (GND); also elsewhere on the board
unnamed: CN2.1, D2.2 (A), R14.2
unnamed: CN2.2, R10.1
unnamed: CN2.4, R15.1
unnamed: CN2.5, R16.1
unnamed: CN2.6, R17.1
unnamed: CN3.1, SB2.1 (A), SB3.2 (B)
unnamed: CN3.2, SB4.1 (A), SB5.2 (B)
unnamed: CN3.3, SB6.1 (A), SB7.2 (B)
unnamed: CN3.4, SB8.1 (A), SB9.2 (B)
unnamed: D1.2 (A), J3.1 (VBUS)
unnamed: D2.1 (K), R2.1
unnamed: C16.1, C17.1, D3.2 (A), U7.5 (VOUT)
unnamed: D4.2 (A), R13.1
unnamed: J3.3 (D+), R1.1, R6.1
unnamed: J3.2 (D-), R7.1
unnamed: J3.4 (ID), R8.1
unnamed: R5.2, U5.44 (BOOT0)
unnamed: R19.2, R20.2, U5.10 (PA0)
unnamed: R66.1, U5.29 (PA8)
unnamed: R12.2, U5.2 (PC13)
unnamed: R11.2, U5.3 (PC14)
unnamed: C8.1, U6.4 (BYP)
unnamed: C15.1, U7.4 (BYP)
VDD: JP2.1; also elsewhere on the board

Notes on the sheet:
Default
Reserved

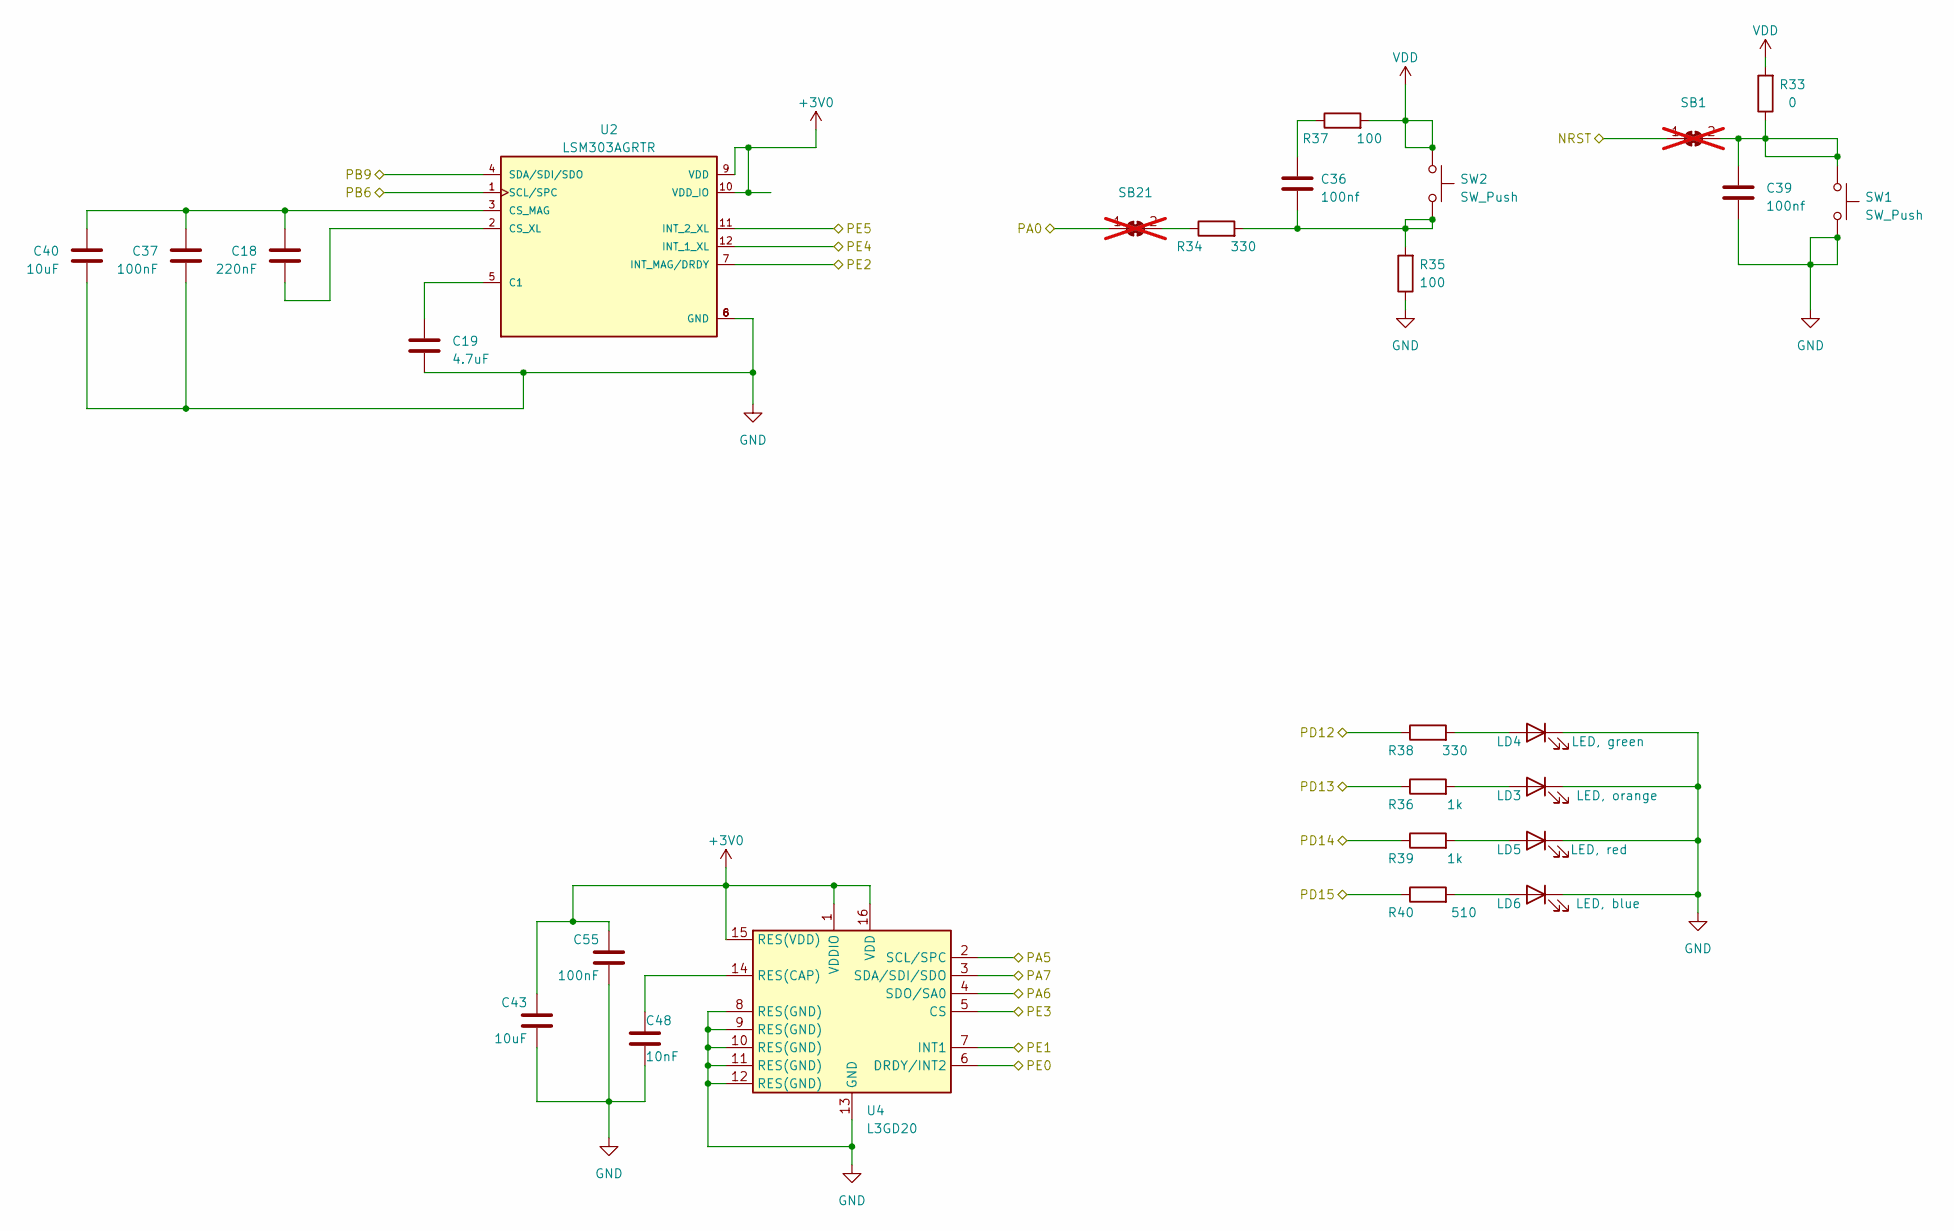
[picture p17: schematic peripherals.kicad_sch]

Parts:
C18: 220nF; C_0402_1005Metric
C19: 4.7uF; C_0402_1005Metric
C36, C39: 100nf; C_0402_1005Metric
C37, C55: 100nF; C_0402_1005Metric
C40, C43: 10uF; C_0402_1005Metric
C48: 10nF; C_0402_1005Metric
LD3: LED, orange; LED_0402_1005Metric
LD4: LED, green; LED_0402_1005Metric
LD5: LED, red; LED_0402_1005Metric
LD6: LED, blue; LED_0402_1005Metric
R33: 0; R_0402_1005Metric
R34, R38: 330; R_0402_1005Metric
R35, R37: 100; R_0402_1005Metric
R36, R39: 1k; R_0402_1005Metric
R40: 510; R_0402_1005Metric
SB1, SB21: SolderJumper_2_Bridged; SolderJumper-2_P1.3mm_Bridged2Bar_Pad1.0x1.5mm; not fitted
SW1, SW2: SW_Push; SW_Push_1P1T_NO_6x6mm_H9.5mm
U2: LSM303AGRTR; LGA12R50P_200X200X100
U4: L3GD20; LGA-16_4x4mm_P0.65mm_LayoutBorder4x4y

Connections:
+3V0: C43.1, C55.1, U2.9 (VDD), U2.10 (VDD_IO), U4.1 (VDDIO), U4.15 (RES(VDD)), U4.16 (VDD); also elsewhere on the board
/NRST: SB1.1 (A); also elsewhere on the board
/PA0: SB21.1 (A); also elsewhere on the board
/PA5: U4.2 (SCL/SPC); also elsewhere on the board
/PA6: U4.4 (SDO/SA0); also elsewhere on the board
/PA7: U4.3 (SDA/SDI/SDO); also elsewhere on the board
/PB6: U2.1 (SCL/SPC); also elsewhere on the board
/PB9: U2.4 (SDA/SDI/SDO); also elsewhere on the board
/PD12: R38.1; also elsewhere on the board
/PD13: R36.1; also elsewhere on the board
/PD14: R39.1; also elsewhere on the board
/PD15: R40.1; also elsewhere on the board
/PE0: U4.6 (DRDY/INT2); also elsewhere on the board
/PE1: U4.7 (INT1); also elsewhere on the board
/PE2: U2.7 (INT_MAG/DRDY); also elsewhere on the board
/PE3: U4.5 (CS); also elsewhere on the board
/PE4: U2.12 (INT_1_XL); also elsewhere on the board
/PE5: U2.11 (INT_2_XL); also elsewhere on the board
GND: C19.2, C37.2, C39.2, C40.2, C43.2, C48.2, C55.2, LD3.1 (K), LD4.1 (K), LD5.1 (K), LD6.1 (K), R35.1, SW1.2, U2.6 (GND), U2.8 (GND), U4.8 (RES(GND)), U4.9 (RES(GND)), U4.10 (RES(GND)), U4.11 (RES(GND)), U4.12 (RES(GND)), U4.13 (GND); also elsewhere on the board
unnamed: C36.1, R37.1
unnamed: C36.2, R34.2, R35.2, SW2.2
unnamed: LD3.2 (A), R36.2
unnamed: LD4.2 (A), R38.2
unnamed: LD5.2 (A), R39.2
unnamed: LD6.2 (A), R40.2
unnamed: C39.1, R33.1, SB1.2 (B), SW1.1
unnamed: R34.1, SB21.2 (B)
unnamed: C19.1, U2.5 (C1)
unnamed: C18.1, C37.1, C40.1, U2.3 (CS_MAG)
unnamed: C18.2, U2.2 (CS_XL)
unnamed: C48.1, U4.14 (RES(CAP))
VDD: R33.2, R37.2, SW2.1; also elsewhere on the board

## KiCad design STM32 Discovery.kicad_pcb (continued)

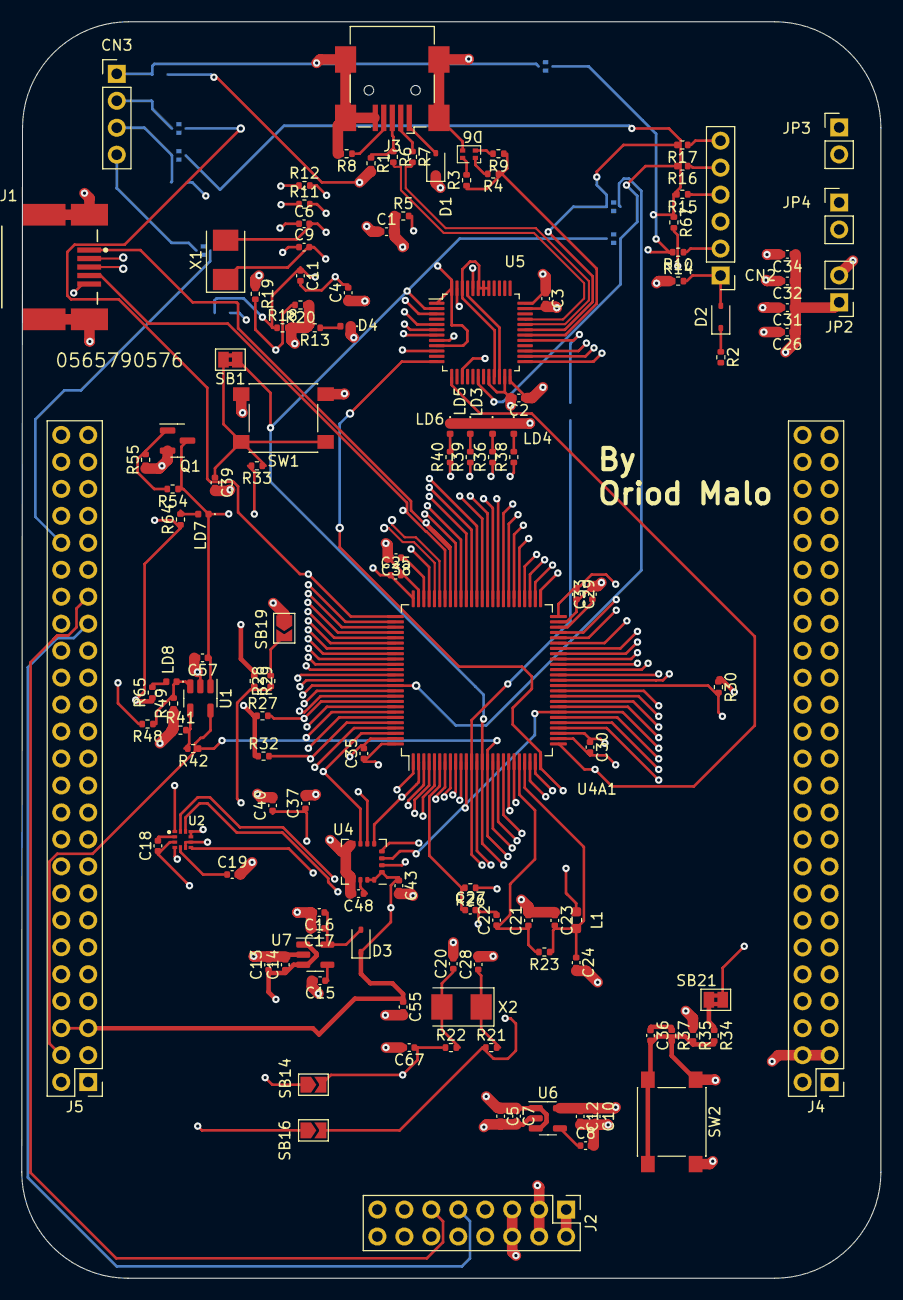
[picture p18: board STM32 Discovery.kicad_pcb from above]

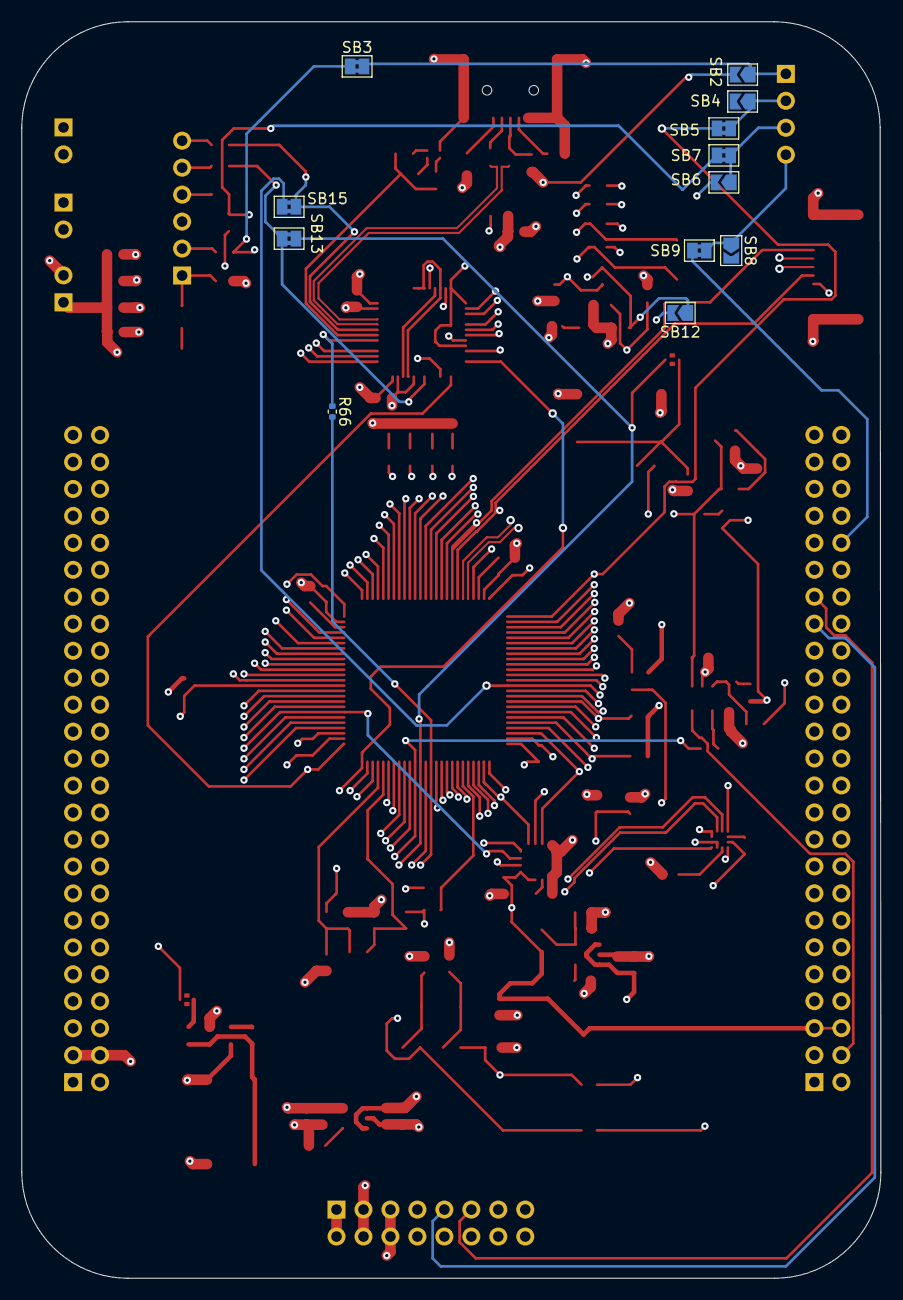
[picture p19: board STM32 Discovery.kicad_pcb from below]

Board: 6 copper layers, 80.9 x 118.4 mm, 142 parts (12 on the bottom side), 154 nets.
